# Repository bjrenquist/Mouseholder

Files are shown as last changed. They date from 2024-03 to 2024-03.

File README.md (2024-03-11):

# Mouseholder
This file includes 3-D printer files for custom mouse holders for lean (< 35g) and obese (up to 55g) mice 

The 3MF files within each folder can be used to print multiple parts simultaneously.  Each holder is composed of 4 printed parts.  The gate is made up of an assembly of the gate bolt, gate handle, and gate.  The chamber is the 4th part.  The holder also includes 3 parts that can be purchased at your local hardware store.  3 parts from hardware store include 1)  Compression Spring 3/4" Length, 7/16" O.D., 0.047" Wastegate, 2) Pan Head, Phillips, Machine Screw 8-32 X 1.5", 3) 8-32 nut (fits with screw, part 2)

To assemble 1) put machine screw into gate_bolt, 2) put spring over gate_bolt, 3) Put gate handle onto gate bolt, 4) put nut in gate, 5) using a Phillps head screwdriver, screw machine screw in gate bolt into nut in gate (continue screwing until it is tight), 6) put gate assembly into chamber.  For most uses you will want the extension on the gate handle to face the mouse.  This prevents the mouse from turning to look out the opening at the top.  However, we flip the gate when dealing with cannulated mice.  

Directions for Assembly and Use contains pictures that accompany these directions.

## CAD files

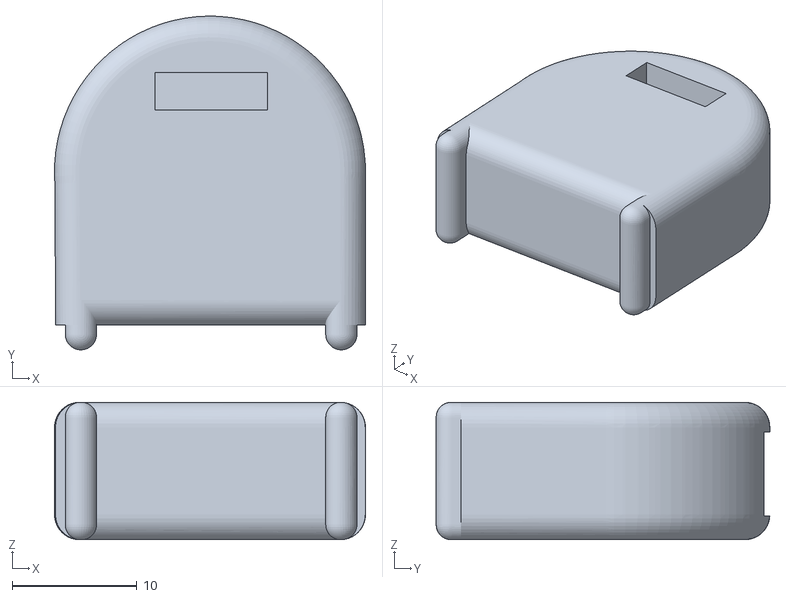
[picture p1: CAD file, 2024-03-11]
Lean Mouse Holder/lean_gate.STL
24.9 x 26.7 x 11.0

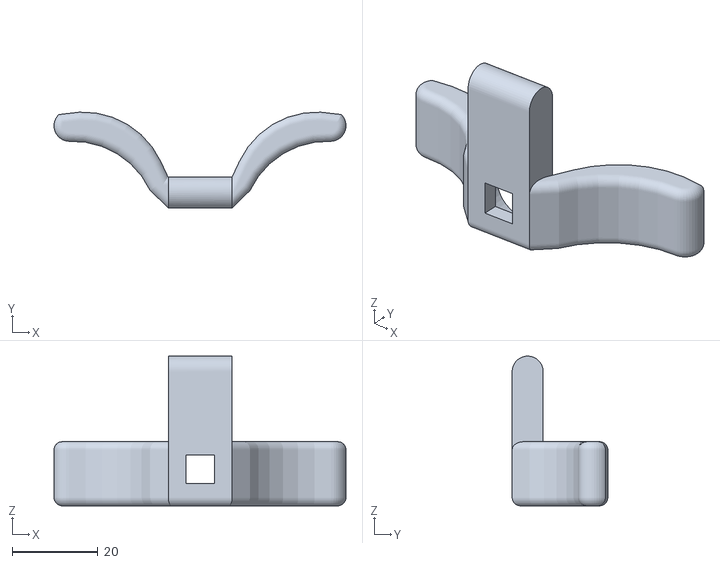
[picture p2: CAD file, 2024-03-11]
Lean Mouse Holder/gate_handle.STL
68.2 x 22.4 x 35.0

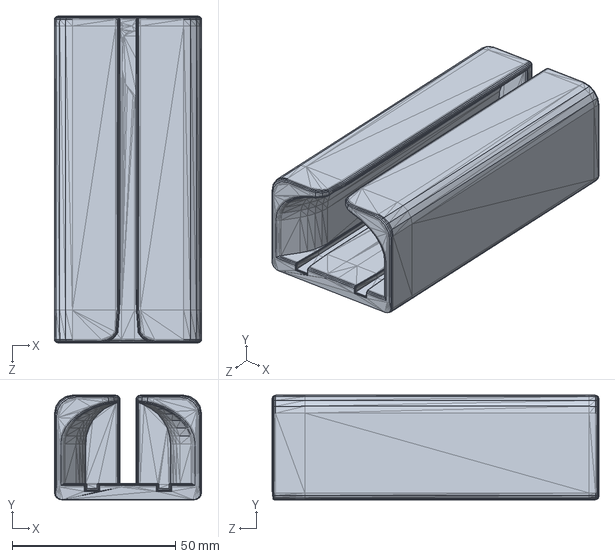
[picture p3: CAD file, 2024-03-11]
Lean Mouse Holder/Lean_Chamber.SLDPRT
45.0 x 32.0 x 100.0 mm

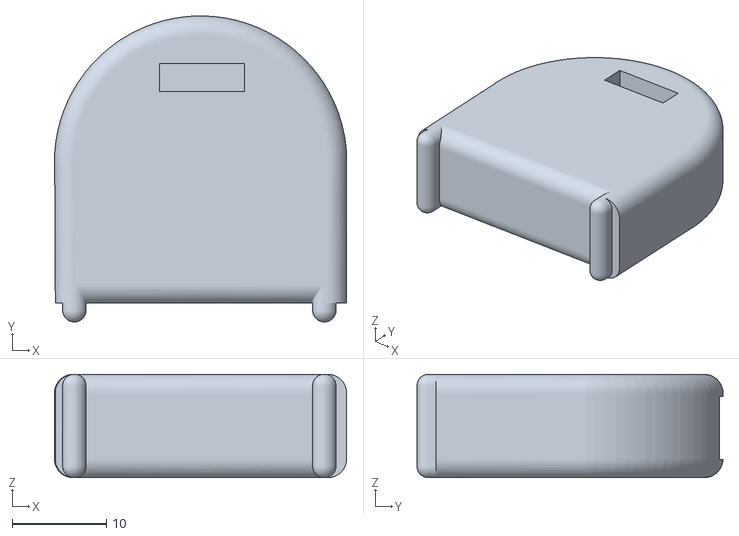
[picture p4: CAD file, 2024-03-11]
Obese Mouse Holder/large_gate.STL
31.1 x 32.6 x 11.0

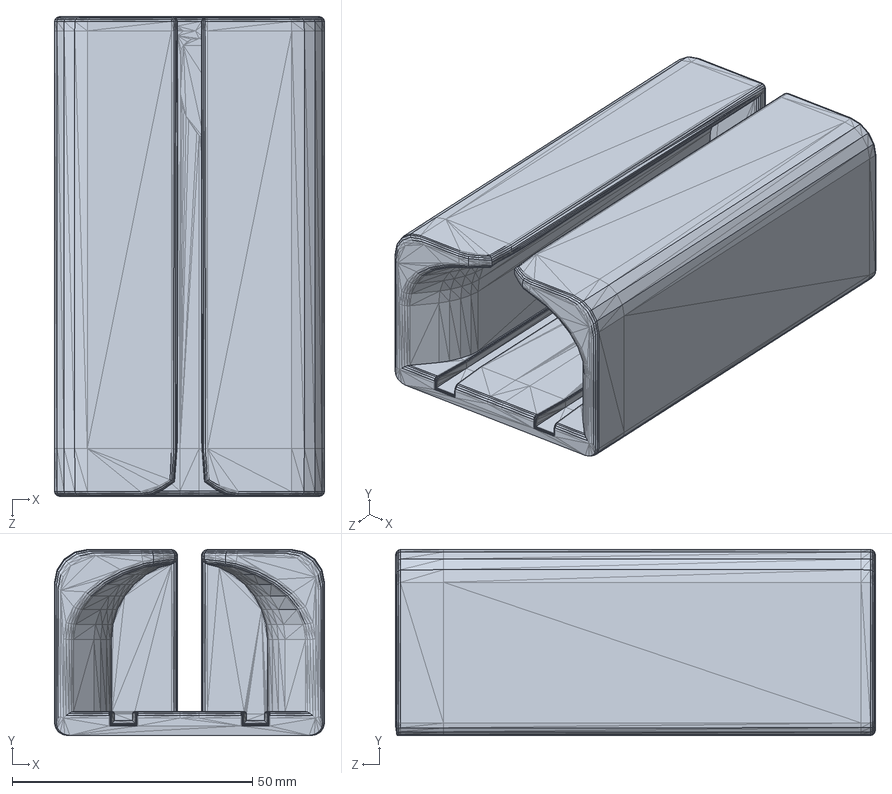
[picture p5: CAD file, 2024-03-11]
Obese Mouse Holder/Obese_Chamber.SLDPRT
56.2 x 38.8 x 100.0 mm

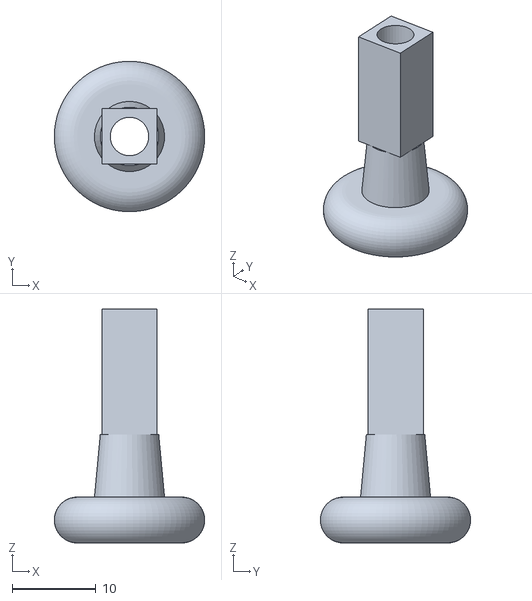
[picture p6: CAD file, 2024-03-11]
Lean Mouse Holder/gate_bolt.STL
18.0 x 18.0 x 28.0

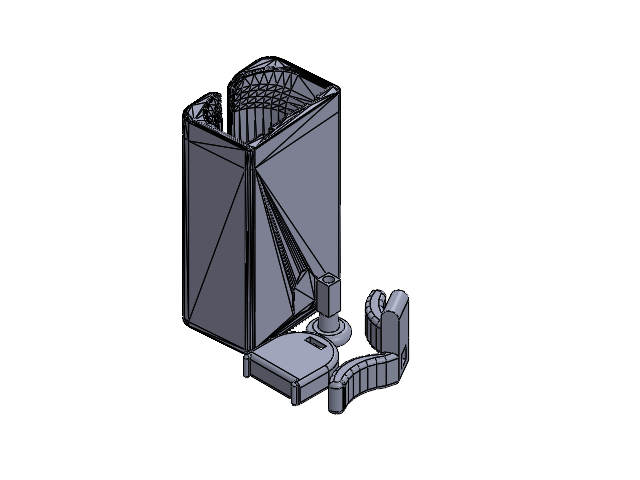
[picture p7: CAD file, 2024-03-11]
Obese Mouse Holder/Obese_All_Parts.SLDASM
gate_bolt_cate
large_gate_cate
gate_handle_cate
Obese_Chamber

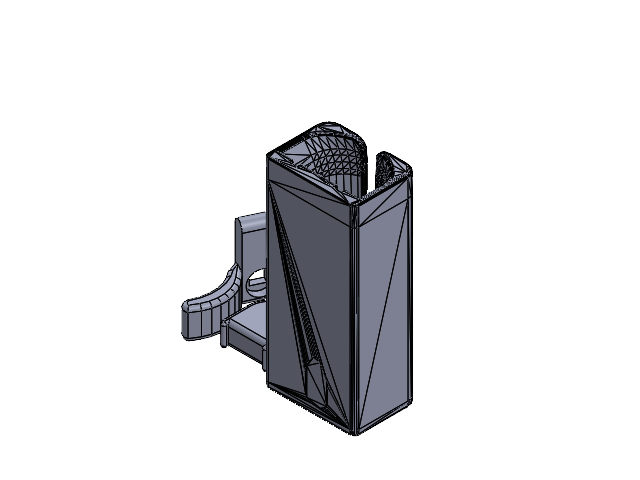
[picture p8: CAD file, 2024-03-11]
Lean Mouse Holder/Lean_All_Parts.SLDASM
gate_bolt_cate
gate_handle_cate
gate_cate
Lean_Chamber

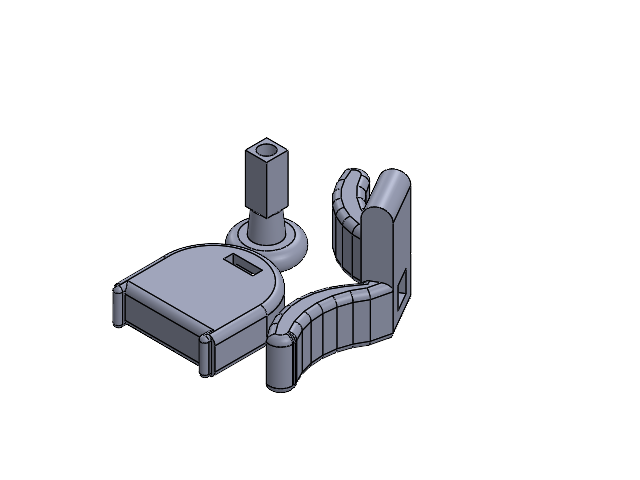
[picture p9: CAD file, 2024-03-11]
Obese Mouse Holder/Obese_Gate_Parts.SLDASM
gate_bolt_cate
large_gate_cate
gate_handle_cate

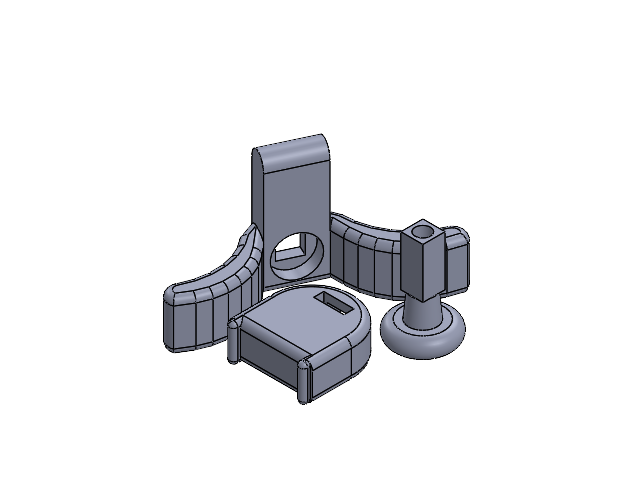
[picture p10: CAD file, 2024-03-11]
Lean Mouse Holder/Lean_Gate_Parts.SLDASM
gate_bolt
gate_handle
lean_gate

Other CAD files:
Lean Mouse Holder/Lean_All_Parts.3MF
Lean Mouse Holder/Lean_Chamber.3MF
Lean Mouse Holder/Lean_Chamber.STL
Lean Mouse Holder/Lean_Gate_Parts.3MF
Obese Mouse Holder/Obese_All_Parts.3MF
Obese Mouse Holder/Obese_Chamber.3MF
Obese Mouse Holder/Obese_Chamber.STL
Obese Mouse Holder/Obese_Gate_Parts.3MF

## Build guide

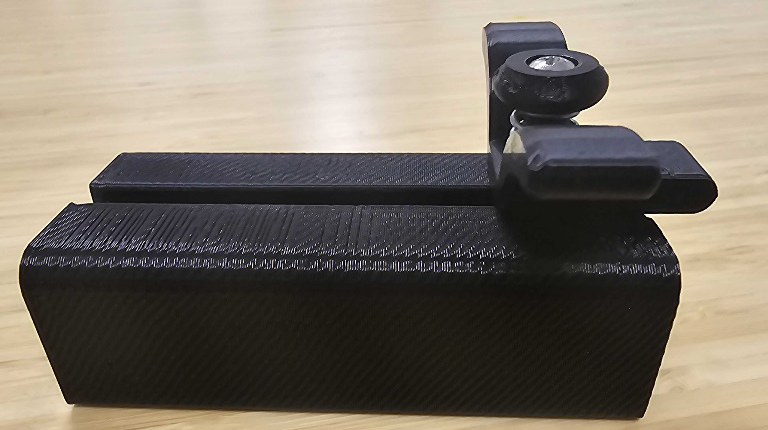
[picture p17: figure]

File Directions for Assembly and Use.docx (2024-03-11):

ReadMe File

Each holder is composed of 4 printed parts. The gate is made up of an assembly of the gate bolt, gate handle, and gate. The chamber is the 4th part. The holder also includes 3 parts that can be purchased at your local hardware store. 3 parts from hardware store include 1) Compression spring 3/4" Length, 7/16" O.D., 0.047" Wastegate, 2) Pan Head, Phillips, Machine Screw 8-32 X 1.5", 3) 8-32 nut (fits with screw, part 2)

To assemble

1) put machine screw into gate bolt

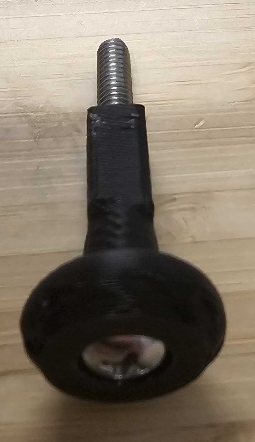
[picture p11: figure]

2) put spring over gate bolt

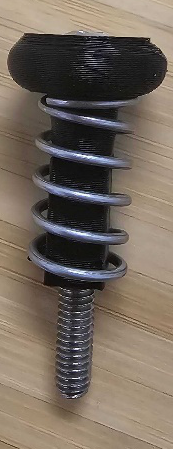
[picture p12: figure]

3) Put gate handle onto gate bolt

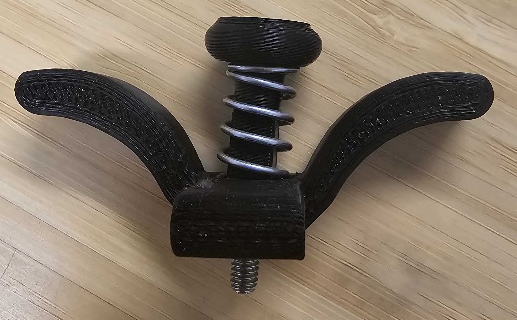
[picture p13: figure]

4) put nut in gate

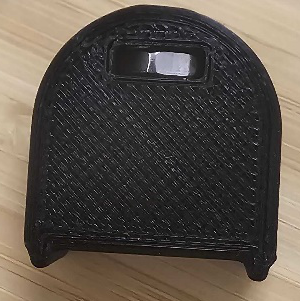
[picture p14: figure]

5) using a Phillips head screwdriver, screw machine screw in gate bolt into nut in gate (continue screwing until it is tight)

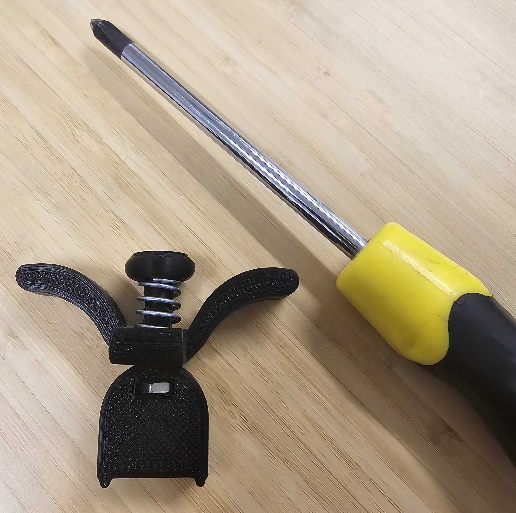
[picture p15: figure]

6) put gate assembly into chamber. For most uses you will want the extension on the gate handle to face the mouse. This prevents the mouse from turning to look out the opening at the top.

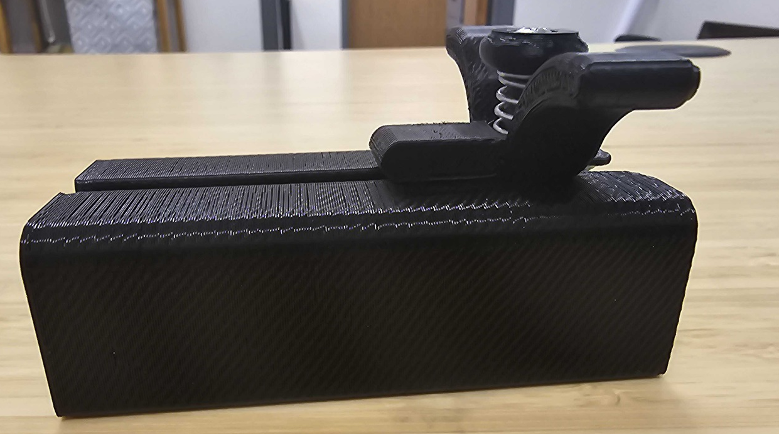
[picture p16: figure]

However, we flip the gate when dealing with cannulated mice. Readme file in each folder contains pictures.
